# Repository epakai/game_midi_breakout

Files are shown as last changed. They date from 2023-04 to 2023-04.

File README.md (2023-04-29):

# Game Midi Breakout

This is my compact hobbyist design for converting game port (DB-15) to MIDI ports. It's made in Kicad. The PCB fits inside a [GOLD-TEK/GTK DH151 connector housing](https://www.taydaelectronics.com/connectors-sockets/d-sub-connectors/d-sub-cover-15-pins-with-short-screw.html).

** Note: This revision is untested. **

The previous revision had incorrect transistor pinouts, but I was able to verify its functionality with a bodge (upside-down transistors). This rev has had minor mods to schematic, and a near-complete re-layout. You're taking a chance I messed something up if you build it without verifying.

Here's what I changed: 

- Schematic
    + Swapped 2N3904 for the correct MMBT3904 transistor (corrects pinout)
    + added capacitors to ground the MIDI cable shield

- PCB layout
    + Caps/Resistors lined up, real nice
    + Silkscreen labels for component references
    + Everything but the OptoIsolator moved around and rerouted

## Pictures

### What you get 
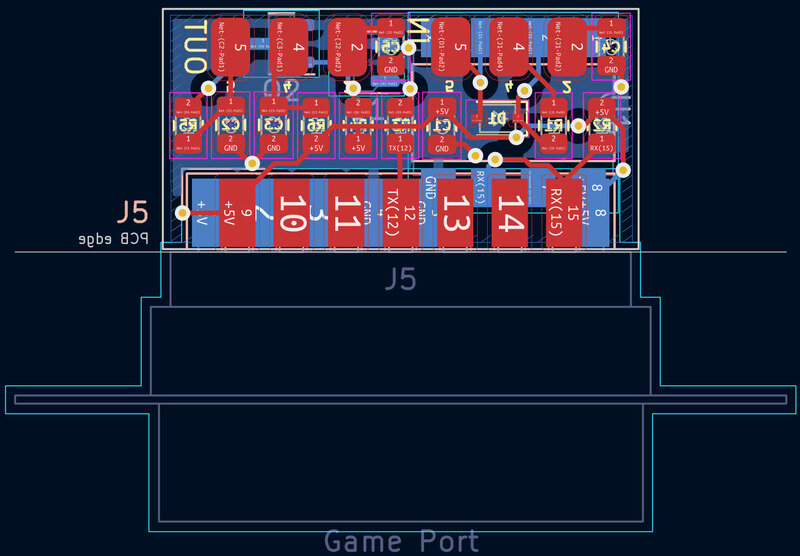
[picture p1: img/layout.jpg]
PCB Layout

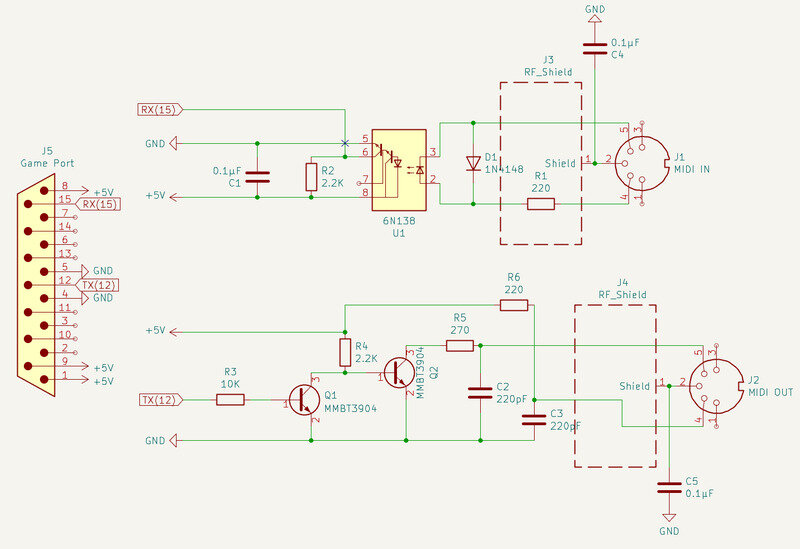
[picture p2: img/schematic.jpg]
Schematic


### My first attempt with all it's warts
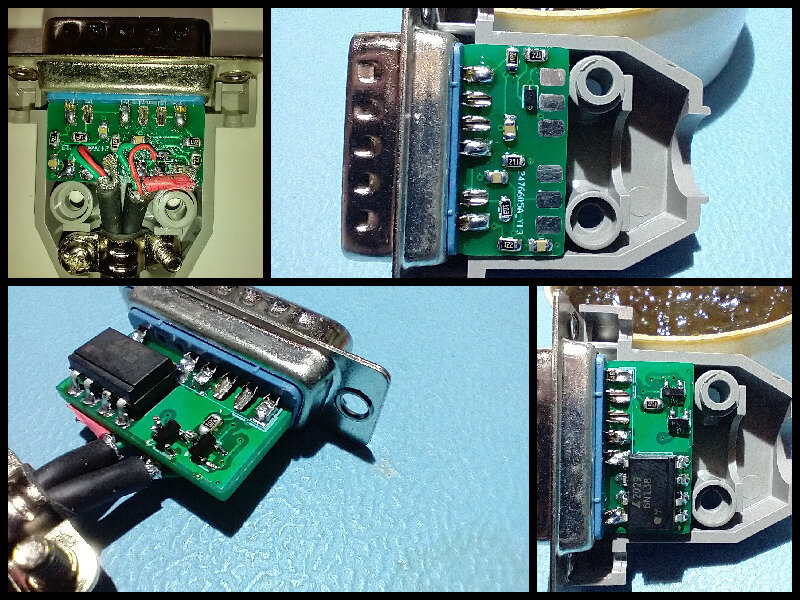
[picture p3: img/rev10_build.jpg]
Rev 1.0 Build


### 3D renders with most of the components
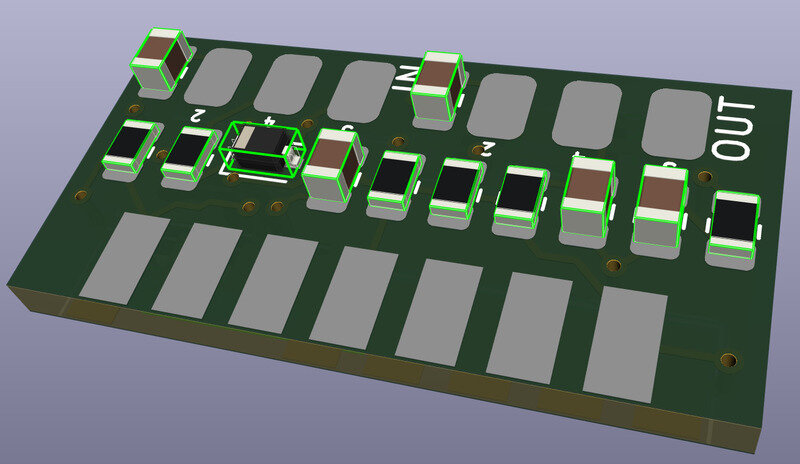
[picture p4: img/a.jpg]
3D Render 1

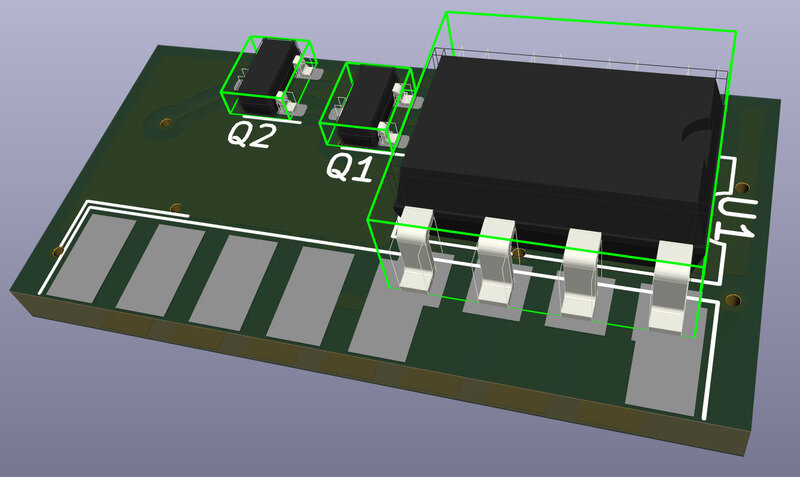
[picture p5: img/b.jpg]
3D Render 2


## BOM

| Quantity | Ref(s) | Value | Mfg Part No. | Description |
|---|---|---|---|---|
| 1 | J5 | - | DA15PT | GTK 15-pin male D-Sub connector |
| 1 | -  | - | DH151PS/RH | GTK 15-pin D-sub cover |
| 1 | U1 | - | 6N138S | Opto-Isolator 5KV Darl w/Base 8SMD |
| 2 | Q1, Q2 | - | MMBT3904 | NPN Transistor 40V 0.2A SOT23-3 | 
| 1 | D1 | - | 1N4148WSTR | Diode 75V 300MA SOD323 | 
| 3 | C1,C4,C5 | 0.1 µF | CL21F104ZBCNNNC | Ceramic Capacitor 50V 0805 |
| 2 | C2,C3 | 220 pF | CL21B221KBANNNC | Ceramic Capacitor 50V 0805 | 
| 2 | R1, R6 | 220 Ω | CR0805-JW-221ELF | SMD Resistor 5% 1/8W 0805 | 
| 1 | R5 | 270 Ω | CR0805-JW-271ELF | SMD Resistor 5% 1/8W 0805 | 
| 2 | R2, R4 | 2.2 KΩ | CR0805-FX-2201ELF | SMD Resistor 1% 1/8W 0805 | 
| 2 | R3 | 10 KΩ | CR0805-JW-103ELF | SMD Resistor 5% 1/8W 0805 | 

Not included are any cables or MIDI connectors. Be creative. You can connect a pair of cables straight to male or female connectors, or run a single cable to a breakout box with a pair of connectors. Just connect IN or OUT if you like, etc.

## Making it

The D-Sub connector has to be modified before soldering. 

- Remove pins 6 and 7. Small pliers work well, wiggle and pull from the back.
- Pins 5 and 8 need to be cut short to make room for the opto-isolator, but you might wait until after U1 is soldered to check the sizing.

Assembly order:
- D1, Q1, Q2
- C1-C3, R1-R6
- C4, C5
- U1
- Remove and cut pins on J5 (15-pin connector) as described above
- J5
- Attach whatever MIDI cable/sockets you prefer

## The Design

The Output circuit comes from [ESS ES1869 Data Sheet, Page 24](https://www.philscomputerlab.com/uploads/3/7/2/3/37231621/es1869techmanual.pdf#page=24).

The Input circuit is similar, but I found the reference at [Teragon Audio](http://midi.teragonaudio.com/hardware/pc_intfc.htm) to be useful, and I took values and components from there.

The PCB is designed to be a close fit inside the connector housing. Rev 1.0 versions I produced at JLCPCB fit well in my initial build.

## Testing

I tested the adapter with a BTC 1853 Card (ES1868F chipset). I was able to transmit and recieve with a MidiMan MidiSport 1x1 USB adaptor. I also transmitted to a Roland MT-90s.

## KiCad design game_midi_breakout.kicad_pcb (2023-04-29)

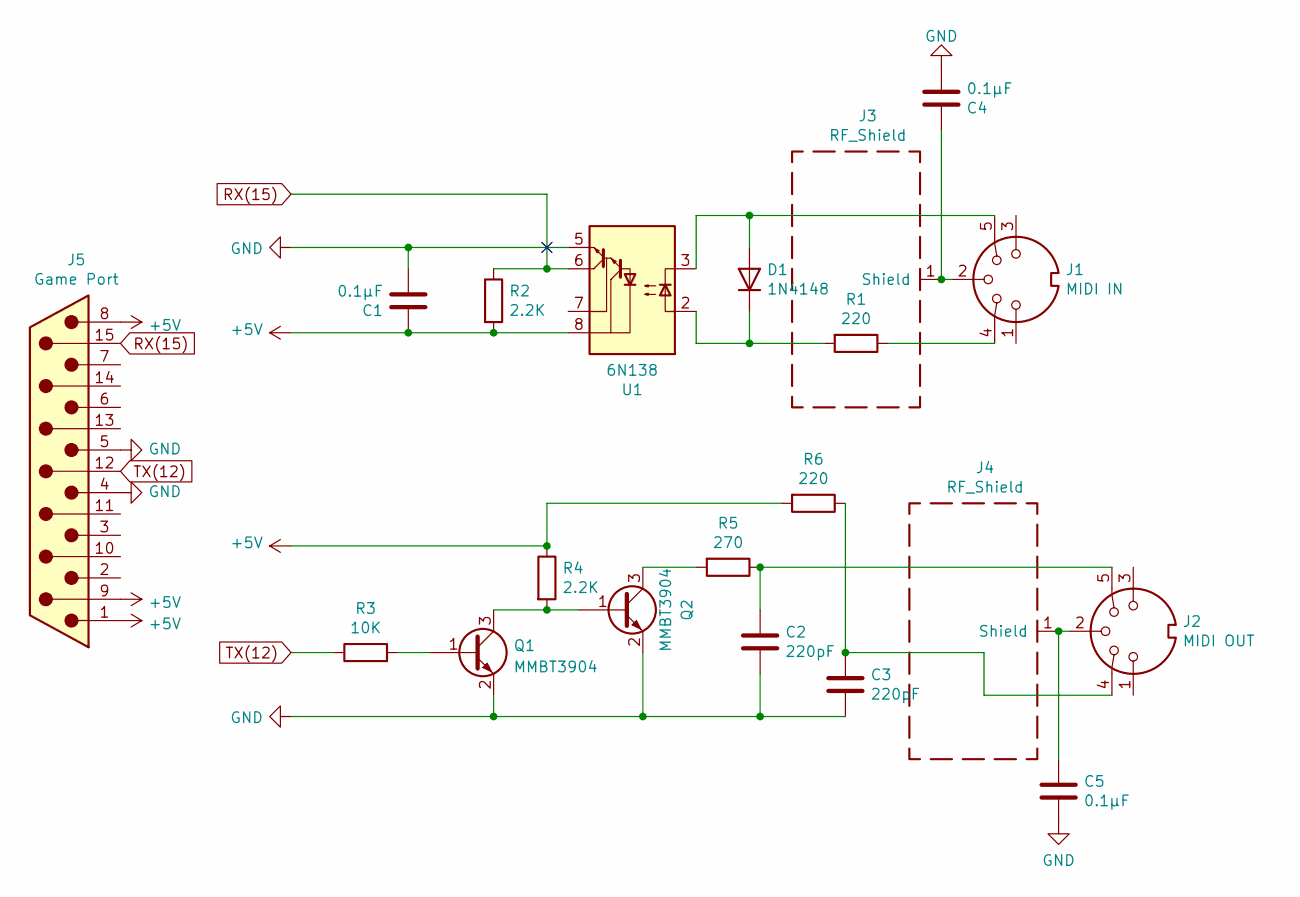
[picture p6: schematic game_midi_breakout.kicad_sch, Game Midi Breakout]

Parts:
C1, C4, C5: 0.1μF; C_0805_2012Metric
C2, C3: 220pF; C_0805_2012Metric
D1: 1N4148; D_SOD-323
J1: MIDI IN; midi pads
J2: MIDI OUT; midi pads
J3, J4: RF_Shield
J5: Game Port; DSUB-15_Male_EdgeMount_P2.77mm
Q1, Q2: MMBT3904; SOT-23
R1, R6: 220; R_0805_2012Metric
R2, R4: 2.2K; R_0805_2012Metric
R3: 10K; R_0805_2012Metric
R5: 270; R_0805_2012Metric
U1: 6N138; SMDIP-8_W7.62mm

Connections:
+5V: C1.1, J5.1, J5.8, J5.9, R2.2, R4.1, R6.2, U1.8 (VCC)
GND: C1.2, C2.2, C3.2, C4.2, C5.2, J5.4, J5.5, Q1.2 (E), Q2.2 (E), U1.5 (GND)
unnamed: C2.1, J2.5, R5.1
unnamed: C3.1, J2.4, R6.1
unnamed: D1.1 (K), R1.2, U1.2 (C1)
unnamed: D1.2 (A), J1.5, U1.3 (C2)
unnamed: C4.1, J1.2, J3.1
unnamed: J1.4, R1.1
unnamed: C5.1, J2.2, J4.1
unnamed: Q1.3 (C), Q2.1 (B), R4.2
unnamed: Q1.1 (B), R3.2
unnamed: Q2.3 (C), R5.2
RX(15): J5.15, R2.1, U1.6 (VO2)
TX(12): J5.12, R3.1

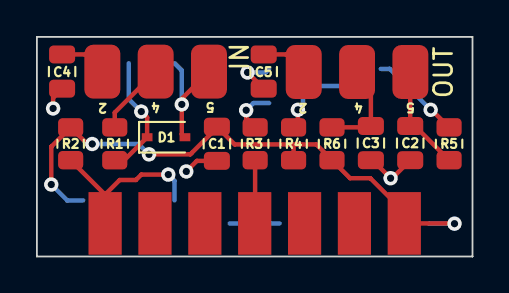
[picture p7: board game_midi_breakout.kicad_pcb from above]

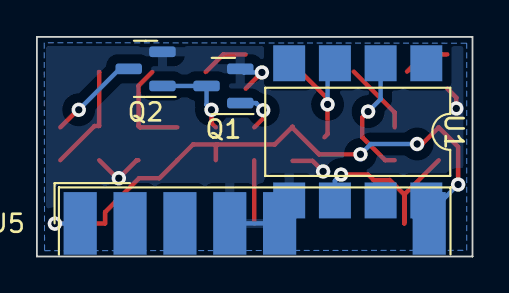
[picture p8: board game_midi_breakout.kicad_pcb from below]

Board: 2 copper layers, 24.2 x 12.2 mm, 18 parts (4 on the bottom side), 14 nets.
